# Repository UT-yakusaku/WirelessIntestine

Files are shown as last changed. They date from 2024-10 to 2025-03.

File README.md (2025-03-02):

This is the code for a paper titiled "Wireless Recording and Autoencoder Denoising of Intestinal Activity in Freely Moving Rats"

# WirelessIntestine

In this repository, we have 3 main components used in our paper.

`kicad/` : PCB and BOM of a custom-made board  
`nrf/` : a custom-made firmware for microcontroller (nrf51822)  
`analysis/model_train.py`: codes for training the denoising autoencoder  

## Building a firmware for nrf51822

Building and flashing firmware were described in the Makefile routines.
Connect the debugger to the microcontroller via JTAG, then build and flash the program using:

```
cd nrf/
make . -B ./_build
make flash_softdevice
```

## Detailed description of methods

Below, detailed description of analysis methods utilized in paper.

## Locomotion index

Locomotion index was calculated by the video of behaving rats in their homecage, recorded at a resolution of 960 by 540 pixels squared at 30 frames per second. As an initial preprocessing step for analyzing rats’ locomotion, video frames were converted to grayscale, with frames extracted every 180 frames (downsampled). The differential between successive frames was employed to quantify the magnitude of locomotion at each temporal point. In calculating this specific differential, the variance between the luminance values in each pixel, ranging from 0 to 255, was computed for every frame and aggregated across the entire frame. These aggregated values were designated as the locomotion levels and interpreted as an index of the rat's activity at specific intervals.
Locomotion levels were measured throughout the entire recording period. Home cage provided a confined space, restricting the variety of locomotion. Given this limitation, we estimated that their movements under these experimental conditions could be classified into two distinct states: moving (behaving) and non-moving (immobile). A Gaussian mixture model (GMM) was used to classify these states and determine the threshold for the locomotion index.

## Calculation of alpha in power-law noises

Alpha (α) is a parameter of power-law noise that defines the slope of the spectrum. Specifically, α is determined by the following relationship:
Where f is the frequency and S(f) is the power spectral density (PSD) of the power-law noise,
S(f) ∝ f ^(-α)
This equation indicates that a higher α corresponds to a steeper spectral slope, while a lower α results in a flatter spectrum in the Fourier-transformed waveforms. 

For the analysis of intestinal movement signals, a Fourier transform was applied to the acquired signals and represented on a double-logarithmic graph (Figure 1C, 2D). The signal comprising 180,000 data points was limited within the frequency range up to 5 Hz resulting in 18,000 points, meticulously smoothed employing a third-order Savitzky-Golay filter with a window size of 51, as executed via the Python Scikit-learn library. For the analysis across both logarithmic graphs, the smoothed signal was resampled at uniformly distributed intervals with a scaling factor of 100.02 in the logarithmic domain to circumvent bias in the subsequent fitting procedure. This precaution addresses the intrinsic characteristic of data sampled in linear space, which predisposes it to contain more data points in high-frequency regions as opposed to the low-frequency areas, resulting in their disproportionate representation when analyzed on a logarithmic scale. The resampled signal to mitigate this biased representation was depicted on a logarithmic scale spanning from 5 × 10⁻⁴ to 5 Hz, and thereafter, it was meticulously fitted with a linear function utilizing the least-squares methodology. This linear fit was employed to estimate a robust baseline for evaluating the strength of intestinal movement and calculate the slope of baseline, interpreted as the alpha.

## Definition of Intestinal Events

The amplitude of intestinal movements was segmented into 10.24-second bins. These amplitudes were then classified into two states—containing or lacking intestinal activity—using a Gaussian mixture model (the number of components is set to 2). Intestinal events were defined as periods in which intestinal activity was present.

## Autoencoder construction and training

### Training datasets

The training data comprised scalograms derived from amplitude-modulated waves, representing pure intestinal movements, amalgamated with pink noise to simulate motion-induced disruptions. The pure signal was modeled as the product of a modulation sine wave (frequency: 0.01-0.2 Hz) and a carrier wave (frequency: 0.5-0.7 Hz), with its intensity and frequency, varied across training samples to introduce diversity. Pink noise, inversely proportional to frequency, was incorporated to emulate movement artifacts, with a 15-fold difference in noise intensity between high- and low-noise conditions. The model was trained with 100 artificial 2000-second waves. The model was engineered to receive the high-noise version of signals as input and produce the low-noise version as output. The dataset was split into training and validation groups at an 8:2 ratio.

### Data preprocessing

For preprocessing, signals were converted into scalograms utilizing a short-term Fourier transform (STFT) with a 10.24-second Hann window, providing a frequency resolution of 0.1 Hz. These scalograms, restricted to the 0.4–6.5 Hz range, were segmented into 655-second segments and resized into 64 × 64 matrices for input into the autoencoder.

### Model construction

The autoencoder architecture comprises three parts: the encoder, bottleneck, and decoder. The encoder first processes the input matrices through a 2D convolutional layer with 32 filters of size 3 × 3, followed by a 2 × 2 max-pooling layer, reducing the matrices to 32 × 32 × 32. A second convolutional layer with identical filter dimensions and another max-pooling layer further reduces the size to 64 × 16 × 16. A 2D convolutional operation is performed in the bottleneck layer, increasing the depth to 128 while maintaining the spatial dimensions.
In the decoder, two upsampling layers, each followed by a convolutional layer, sequentially doubled the spatial dimensions and reduced the depth, ultimately restoring the matrices to 32 × 64 × 64. The final convolutional layer employed a linear activation function to conform the output to the input dimensions.

### Training

The model was trained to utilize the Adam optimizer with a learning rate of 0.001 and mean squared error (MSE) as the loss function. The training was confined to 100 epochs, with the learning rate reduced by a factor of 0.1 after five epochs without improvement. If no improvement was observed after ten epochs, training was stopped early. All routines were implemented using Python TensorFlow and Keras libraries.

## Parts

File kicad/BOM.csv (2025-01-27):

Item # | Ref Des | Qty | Manufacturer | Mfg Part # | Description / Value | Package | Type
1 | U1 | 1 | Analog Devices | AD8237ARMZ | IC AMP MSOP-8 | MSOP-8_3x3mm_P0.65mm | SMD
2 | U2 | 1 | Texas Instruments | ADS1113IDGST | IC ADC 16BITS 860SPS VSSOP-10 | VSSOP-10_3x3mm_P0.5mm | SMD
3 | U3 | 1 | Texas Instruments | TLV71330PDBVR | IC LDO REG SOT-23-5 | SOT-23-5 | SMD
4 | R1,R2,R3 | 3 | Panasonic | ERA-3AEB121V | RES 120 OHM 0.1% 0603 SMD | R_0603_1608Metric | SMD
5 | R4,R5 | 2 | ROHM | MCR03ERTF4300 | RES 430 OHM 1.0% 0603 SMD | R_0603_1608Metric | SMD
6 | R6 | 1 | Panasonic | ERA-3AED104V | RES 100K OHM 0.5% 0603 SMD | R_0603_1608Metric | SMD
7 | R7,R8 | 2 | ROHM | MCR01MZPF1002 | RES 10K OHM 1.0% 0603 SMD | R_0402_1005Metric | SMD
8 | C1,C2,C3,C4 | 4 | TDK | C1005X5R1V104K | CAP MLCC 0.1UF 0402 SMD | C_0402_1005Metric | SMD
9 | C5 | 1 | TDK | CGA6N2C0G2A473J | CAP MLCC .047UF 3225 SMD | C_1210_3225Metric | SMD

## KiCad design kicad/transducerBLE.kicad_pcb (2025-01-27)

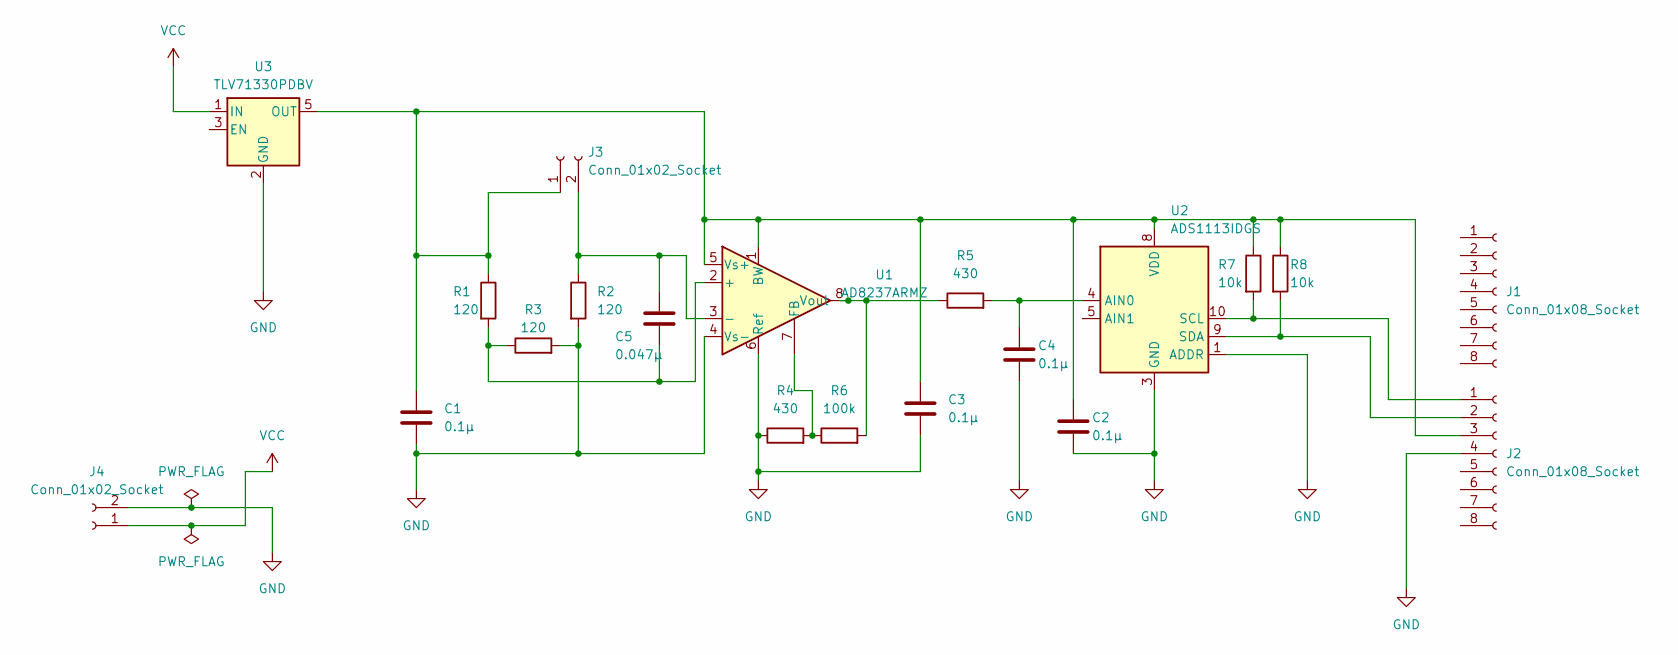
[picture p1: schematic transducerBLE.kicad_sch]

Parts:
C1, C2, C3, C4: 0.1µ; C_0402_1005Metric
C5: 0.047µ; C_1210_3225Metric
J1, J2: Conn_01x08_Socket; PinSocket_1x08_P2.54mm_Vertical
J3, J4: Conn_01x02_Socket; PinSocket_1x02_P2.00mm_Horizontal
R1, R2, R3: 120; R_0603_1608Metric
R4, R5: 430; R_0603_1608Metric
R6: 100k; R_0603_1608Metric
R7, R8: 10k; R_0402_1005Metric
U1: AD8237ARMZ; MSOP-8_3x3mm_P0.65mm
U2: ADS1113IDGS; TSSOP-10_3x3mm_P0.5mm
U3: TLV71330PDBV; SOT-23-5

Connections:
GND: C1.2, C2.2, C3.2, C4.2, J2.4, J4.2, R2.2, R3.2, R4.1, U1.4 (Vs-), U1.6 (Ref), U2.1 (ADDR), U2.3 (GND), U3.2 (GND)
unnamed: J2.1, R7.2, U2.10 (SCL)
unnamed: J2.2, R8.2, U2.9 (SDA)
unnamed: C1.1, C2.1, C3.1, J2.3, J3.1, R1.1, R7.1, R8.1, U1.1 (BW), U1.5 (Vs+), U2.8 (VDD), U3.5 (OUT)
unnamed: C5.1, J3.2, R2.1, U1.3 (-)
unnamed: C5.2, R1.2, R3.1, U1.2 (+)
unnamed: R4.2, R6.1, U1.7 (FB)
unnamed: R5.1, R6.2, U1.8 (Vout)
unnamed: C4.1, R5.2, U2.4 (AIN0)
VCC: J4.1, U3.1 (IN)

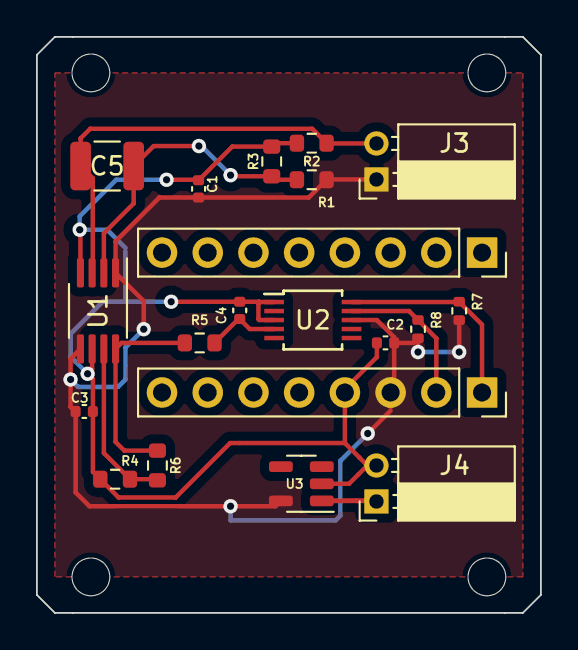
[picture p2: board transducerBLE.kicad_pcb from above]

Board: 2 copper layers, 28.0 x 32.0 mm, 20 parts (0 on the bottom side), 10 nets.

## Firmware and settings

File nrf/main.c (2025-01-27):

/**
 * Copyright (c) 2014 - 2017, Nordic Semiconductor ASA
 * 
 * All rights reserved.
 * 
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
 * 3. Neither the name of Nordic Semiconductor ASA nor the names of its
 *    contributors may be used to endorse or promote products derived from this
 *    software without specific prior written permission.
 * 
 * 4. This software, with or without modification, must only be used with a
 *    Nordic Semiconductor ASA integrated circuit.
 * 
 * 5. Any software provided in binary form under this license must not be reverse
 *    engineered, decompiled, modified and/or disassembled.
 * 
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
 */

/** @file
 *
 * @defgroup ble_sdk_uart_over_ble_main main.c
 * @{
 * @ingroup  ble_sdk_app_nus_eval
 * @brief    UART over BLE application main file.
 *
 * This file contains the source code for a sample application that uses the Nordic UART service.
 * This application uses the @ref srvlib_conn_params module.
 */

#include <stdint.h>
#include <string.h>
#include "nordic_common.h"
#include "nrf.h"
#include "ble_hci.h"
#include "ble_advdata.h"
#include "ble_advertising.h"
#include "ble_conn_params.h"
#include "softdevice_handler.h"
#include "app_timer.h"
#include "app_button.h"
#include "ble_nus.h"
#include "app_uart.h"
#include "app_util_platform.h"
#include "bsp.h"
#include "bsp_btn_ble.h"
#include "drivers_nrf/timer/nrf_drv_timer.h"
#include "drivers_nrf/twi_master/nrf_drv_twi.h"

#define IS_SRVC_CHANGED_CHARACT_PRESENT 0                                           /**< Include the service_changed characteristic. If not enabled, the server's database cannot be changed for the lifetime of the device. */

#if (NRF_SD_BLE_API_VERSION == 3)
#define NRF_BLE_MAX_MTU_SIZE            GATT_MTU_SIZE_DEFAULT                       /**< MTU size used in the softdevice enabling and to reply to a BLE_GATTS_EVT_EXCHANGE_MTU_REQUEST event. */
#endif

#define APP_FEATURE_NOT_SUPPORTED       BLE_GATT_STATUS_ATTERR_APP_BEGIN + 2        /**< Reply when unsupported features are requested. */

#define CENTRAL_LINK_COUNT              0                                           /**< Number of central links used by the application. When changing this number remember to adjust the RAM settings*/
#define PERIPHERAL_LINK_COUNT           1                                           /**< Number of peripheral links used by the application. When changing this number remember to adjust the RAM settings*/

#define DEVICE_NAME                     "Nordic_UART"                               /**< Name of device. Will be included in the advertising data. */
#define NUS_SERVICE_UUID_TYPE           BLE_UUID_TYPE_VENDOR_BEGIN                  /**< UUID type for the Nordic UART Service (vendor specific). */

#define APP_ADV_INTERVAL                256//64                                          /**< The advertising interval (in units of 0.625 ms. This value corresponds to 40 ms). */
#define APP_ADV_TIMEOUT_IN_SECONDS      0                                           /**< The advertising timeout (in units of seconds). */

#define APP_TIMER_PRESCALER             0                                           /**< Value of the RTC1 PRESCALER register. */
#define APP_TIMER_OP_QUEUE_SIZE         4                                           /**< Size of timer operation queues. */

#define MIN_CONN_INTERVAL               MSEC_TO_UNITS(20, UNIT_1_25_MS)             /**< Minimum acceptable connection interval (20 ms), Connection interval uses 1.25 ms units. */
#define MAX_CONN_INTERVAL               MSEC_TO_UNITS(75, UNIT_1_25_MS)             /**< Maximum acceptable connection interval (75 ms), Connection interval uses 1.25 ms units. */
#define SLAVE_LATENCY                   0                                           /**< Slave latency. */
#define CONN_SUP_TIMEOUT                MSEC_TO_UNITS(4000, UNIT_10_MS)             /**< Connection supervisory timeout (4 seconds), Supervision Timeout uses 10 ms units. */
#define FIRST_CONN_PARAMS_UPDATE_DELAY  APP_TIMER_TICKS(5000, APP_TIMER_PRESCALER)  /**< Time from initiating event (connect or start of notification) to first time sd_ble_gap_conn_param_update is called (5 seconds). */
#define NEXT_CONN_PARAMS_UPDATE_DELAY   APP_TIMER_TICKS(30000, APP_TIMER_PRESCALER) /**< Time between each call to sd_ble_gap_conn_param_update after the first call (30 seconds). */
#define MAX_CONN_PARAMS_UPDATE_COUNT    3                                           /**< Number of attempts before giving up the connection parameter negotiation. */

#define DEAD_BEEF                       0xDEADBEEF                                  /**< Value used as error code on stack dump, can be used to identify stack location on stack unwind. */

#define UART_TX_BUF_SIZE                256                                         /**< UART TX buffer size. */
#define UART_RX_BUF_SIZE                256                                         /**< UART RX buffer size. */

static ble_nus_t                        m_nus;                                      /**< Structure to identify the Nordic UART Service. */
static uint16_t                         m_conn_handle = BLE_CONN_HANDLE_INVALID;    /**< Handle of the current connection. */

static ble_uuid_t                       m_adv_uuids[] = {{BLE_UUID_NUS_SERVICE, NUS_SERVICE_UUID_TYPE}};  /**< Universally unique service identifier. */

#define SAMPLE_RATE                     100
#define LOOP_DURATION                   31250 / SAMPLE_RATE

#define TWI_INSTANCE_ID                 0                                           /* TWI instance ID. */
#define TWI_TIMEOUT 			        10000 
#define ADS1115_ADDR                    0x48U                                       /* Common addresses definition for temperature sensor. */
#define SCL_PIN                         17
#define SDA_PIN                         23

#define SWAP(a, b) do { a ^= b; b ^= a; a ^= b; } while(0)

static const nrf_drv_twi_t m_twi        = NRF_DRV_TWI_INSTANCE(TWI_INSTANCE_ID);    /* TWI instance. */
volatile static bool twi_tx_done = false;
volatile static bool twi_rx_done = false;

volatile static uint8_t data_buf[20];
volatile static uint8_t data_buf_to_send[20];
volatile static int8_t data_buf_seek = 0;
volatile static bool data_send_lock = false;

/**@brief Function for assert macro callback.
 *
 * @details This function will be called in case of an assert in the SoftDevice.
 *
 * @warning This handler is an example only and does not fit a final product. You need to analyse
 *          how your product is supposed to react in case of Assert.
 * @warning On assert from the SoftDevice, the system can only recover on reset.
 *
 * @param[in] line_num    Line number of the failing ASSERT call.
 * @param[in] p_file_name File name of the failing ASSERT call.
 */
void assert_nrf_callback(uint16_t line_num, const uint8_t * p_file_name)
{
    app_error_handler(DEAD_BEEF, line_num, p_file_name);
}


/**@brief Function for the GAP initialization.
 *
 * @details This function will set up all the necessary GAP (Generic Access Profile) parameters of
 *          the device. It also sets the permissions and appearance.
 */
static void gap_params_init(void)
{
    uint32_t                err_code;
    ble_gap_conn_params_t   gap_conn_params;
    ble_gap_conn_sec_mode_t sec_mode;

    BLE_GAP_CONN_SEC_MODE_SET_OPEN(&sec_mode);

    err_code = sd_ble_gap_device_name_set(&sec_mode,
                                          (const uint8_t *) DEVICE_NAME,
                                          strlen(DEVICE_NAME));
    APP_ERROR_CHECK(err_code);

    memset(&gap_conn_params, 0, sizeof(gap_conn_params));

    gap_conn_params.min_conn_interval = MIN_CONN_INTERVAL;
    gap_conn_params.max_conn_interval = MAX_CONN_INTERVAL;
    gap_conn_params.slave_latency     = SLAVE_LATENCY;
    gap_conn_params.conn_sup_timeout  = CONN_SUP_TIMEOUT;

    err_code = sd_ble_gap_ppcp_set(&gap_conn_params);
    APP_ERROR_CHECK(err_code);
}


/**@brief Function for handling the data from the Nordic UART Service.
 *
 * @details This function will process the data received from the Nordic UART BLE Service and send
 *          it to the UART module.
 *
 * @param[in] p_nus    Nordic UART Service structure.
 * @param[in] p_data   Data to be send to UART module.
 * @param[in] length   Length of the data.
 */
/**@snippet [Handling the data received over BLE] */
static void nus_data_handler(ble_nus_t * p_nus, uint8_t * p_data, uint16_t length)
{
    for (uint32_t i = 0; i < length; i++)
    {
        while (app_uart_put(p_data[i]) != NRF_SUCCESS);
    }
    while (app_uart_put('\r') != NRF_SUCCESS);
    while (app_uart_put('\n') != NRF_SUCCESS);
}
/**@snippet [Handling the data received over BLE] */


/**@brief Function for initializing services that will be used by the application.
 */
static void services_init(void)
{
    uint32_t       err_code;
    ble_nus_init_t nus_init;

    memset(&nus_init, 0, sizeof(nus_init));

    nus_init.data_handler = nus_data_handler;

    err_code = ble_nus_init(&m_nus, &nus_init);
    APP_ERROR_CHECK(err_code);
}


/**@brief Function for handling an event from the Connection Parameters Module.
 *
 * @details This function will be called for all events in the Connection Parameters Module
 *          which are passed to the application.
 *
 * @note All this function does is to disconnect. This could have been done by simply setting
 *       the disconnect_on_fail config parameter, but instead we use the event handler
 *       mechanism to demonstrate its use.
 *
 * @param[in] p_evt  Event received from the Connection Parameters Module.
 */
static void on_conn_params_evt(ble_conn_params_evt_t * p_evt)
{
    uint32_t err_code;

    if (p_evt->evt_type == BLE_CONN_PARAMS_EVT_FAILED)
    {
        err_code = sd_ble_gap_disconnect(m_conn_handle, BLE_HCI_CONN_INTERVAL_UNACCEPTABLE);
        APP_ERROR_CHECK(err_code);
    }
}


/**@brief Function for handling errors from the Connection Parameters module.
 *
 * @param[in] nrf_error  Error code containing information about what went wrong.
 */
static void conn_params_error_handler(uint32_t nrf_error)
{
    APP_ERROR_HANDLER(nrf_error);
}


/**@brief Function for initializing the Connection Parameters module.
 */
static void conn_params_init(void)
{
    uint32_t               err_code;
    ble_conn_params_init_t cp_init;

    memset(&cp_init, 0, sizeof(cp_init));

    cp_init.p_conn_params                  = NULL;
    cp_init.first_conn_params_update_delay = FIRST_CONN_PARAMS_UPDATE_DELAY;
    cp_init.next_conn_params_update_delay  = NEXT_CONN_PARAMS_UPDATE_DELAY;
    cp_init.max_conn_params_update_count   = MAX_CONN_PARAMS_UPDATE_COUNT;
    cp_init.start_on_notify_cccd_handle    = BLE_GATT_HANDLE_INVALID;
    cp_init.disconnect_on_fail             = false;
    cp_init.evt_handler                    = on_conn_params_evt;
    cp_init.error_handler                  = conn_params_error_handler;

    err_code = ble_conn_params_init(&cp_init);
    APP_ERROR_CHECK(err_code);
}


/**@brief Function for putting the chip into sleep mode.
 *
 * @note This function will not return.
 */
static void sleep_mode_enter(void)
{
    uint32_t err_code = bsp_indication_set(BSP_INDICATE_IDLE);
    APP_ERROR_CHECK(err_code);

    // Prepare wakeup buttons.
    err_code = bsp_btn_ble_sleep_mode_prepare();
    APP_ERROR_CHECK(err_code);

    // Go to system-off mode (this function will not return; wakeup will cause a reset).
    err_code = sd_power_system_off();
    APP_ERROR_CHECK(err_code);
}


/**@brief Function for handling advertising events.
 *
 * @details This function will be called for advertising events which are passed to the application.
 *
 * @param[in] ble_adv_evt  Advertising event.
 */
static void on_adv_evt(ble_adv_evt_t ble_adv_evt)
{
    uint32_t err_code;

    switch (ble_adv_evt)
    {
        case BLE_ADV_EVT_FAST:
            err_code = bsp_indication_set(BSP_INDICATE_ADVERTISING);
            APP_ERROR_CHECK(err_code);
            break;
        case BLE_ADV_EVT_IDLE:
            sleep_mode_enter();
            break;
        default:
            break;
    }
}


/**@brief Function for the application's SoftDevice event handler.
 *
 * @param[in] p_ble_evt SoftDevice event.
 */
static void on_ble_evt(ble_evt_t * p_ble_evt)
{
    uint32_t err_code;

    switch (p_ble_evt->header.evt_id)
    {
        case BLE_GAP_EVT_CONNECTED:
            err_code = bsp_indication_set(BSP_INDICATE_CONNECTED);
            APP_ERROR_CHECK(err_code);
            m_conn_handle = p_ble_evt->evt.gap_evt.conn_handle;
            break; // BLE_GAP_EVT_CONNECTED

        case BLE_GAP_EVT_DISCONNECTED:
            err_code = bsp_indication_set(BSP_INDICATE_IDLE);
            APP_ERROR_CHECK(err_code);
            m_conn_handle = BLE_CONN_HANDLE_INVALID;
            break; // BLE_GAP_EVT_DISCONNECTED

        case BLE_GAP_EVT_SEC_PARAMS_REQUEST:
            // Pairing not supported
            err_code = sd_ble_gap_sec_params_reply(m_conn_handle, BLE_GAP_SEC_STATUS_PAIRING_NOT_SUPP, NULL, NULL);
            APP_ERROR_CHECK(err_code);
            break; // BLE_GAP_EVT_SEC_PARAMS_REQUEST

        case BLE_GATTS_EVT_SYS_ATTR_MISSING:
            // No system attributes have been stored.
            err_code = sd_ble_gatts_sys_attr_set(m_conn_handle, NULL, 0, 0);
            APP_ERROR_CHECK(err_code);
            break; // BLE_GATTS_EVT_SYS_ATTR_MISSING

        case BLE_GATTC_EVT_TIMEOUT:
            // Disconnect on GATT Client timeout event.
            err_code = sd_ble_gap_disconnect(p_ble_evt->evt.gattc_evt.conn_handle,
                                             BLE_HCI_REMOTE_USER_TERMINATED_CONNECTION);
            APP_ERROR_CHECK(err_code);
            break; // BLE_GATTC_EVT_TIMEOUT

        case BLE_GATTS_EVT_TIMEOUT:
            // Disconnect on GATT Server timeout event.
            err_code = sd_ble_gap_disconnect(p_ble_evt->evt.gatts_evt.conn_handle,
                                             BLE_HCI_REMOTE_USER_TERMINATED_CONNECTION);
            APP_ERROR_CHECK(err_code);
            break; // BLE_GATTS_EVT_TIMEOUT

        case BLE_EVT_USER_MEM_REQUEST:
            err_code = sd_ble_user_mem_reply(p_ble_evt->evt.gattc_evt.conn_handle, NULL);
            APP_ERROR_CHECK(err_code);
            break; // BLE_EVT_USER_MEM_REQUEST

        case BLE_GATTS_EVT_RW_AUTHORIZE_REQUEST:
        {
            ble_gatts_evt_rw_authorize_request_t  req;
            ble_gatts_rw_authorize_reply_params_t auth_reply;

            req = p_ble_evt->evt.gatts_evt.params.authorize_request;

            if (req.type != BLE_GATTS_AUTHORIZE_TYPE_INVALID)
            {
                if ((req.request.write.op == BLE_GATTS_OP_PREP_WRITE_REQ)     ||
                    (req.request.write.op == BLE_GATTS_OP_EXEC_WRITE_REQ_NOW) ||
                    (req.request.write.op == BLE_GATTS_OP_EXEC_WRITE_REQ_CANCEL))
                {
                    if (req.type == BLE_GATTS_AUTHORIZE_TYPE_WRITE)
                    {
                        auth_reply.type = BLE_GATTS_AUTHORIZE_TYPE_WRITE;
                    }
                    else
                    {
                        auth_reply.type = BLE_GATTS_AUTHORIZE_TYPE_READ;
                    }
                    auth_reply.params.write.gatt_status = APP_FEATURE_NOT_SUPPORTED;
                    err_code = sd_ble_gatts_rw_authorize_reply(p_ble_evt->evt.gatts_evt.conn_handle,
                                                               &auth_reply);
                    APP_ERROR_CHECK(err_code);
                }
            }
        } break; // BLE_GATTS_EVT_RW_AUTHORIZE_REQUEST

#if (NRF_SD_BLE_API_VERSION == 3)
        case BLE_GATTS_EVT_EXCHANGE_MTU_REQUEST:
            err_code = sd_ble_gatts_exchange_mtu_reply(p_ble_evt->evt.gatts_evt.conn_handle,
                                                       NRF_BLE_MAX_MTU_SIZE);
            APP_ERROR_CHECK(err_code);
            break; // BLE_GATTS_EVT_EXCHANGE_MTU_REQUEST
#endif

        default:
            // No implementation needed.
            break;
    }
}


/**@brief Function for dispatching a SoftDevice event to all modules with a SoftDevice
 *        event handler.
 *
 * @details This function is called from the SoftDevice event interrupt handler after a
 *          SoftDevice event has been received.
 *
 * @param[in] p_ble_evt  SoftDevice event.
 */
static void ble_evt_dispatch(ble_evt_t * p_ble_evt)
{
    ble_conn_params_on_ble_evt(p_ble_evt);
    ble_nus_on_ble_evt(&m_nus, p_ble_evt);
    on_ble_evt(p_ble_evt);
    ble_advertising_on_ble_evt(p_ble_evt);
    bsp_btn_ble_on_ble_evt(p_ble_evt);

}


/**@brief Function for the SoftDevice initialization.
 *
 * @details This function initializes the SoftDevice and the BLE event interrupt.
 */
static void ble_stack_init(void)
{
    uint32_t err_code;

    //nrf_clock_lf_cfg_t clock_lf_cfg = NRF_CLOCK_LFCLKSRC;
    nrf_clock_lf_cfg_t clock_lf_cfg;
    clock_lf_cfg.rc_ctiv = 16;
    clock_lf_cfg.rc_temp_ctiv = 2;
    clock_lf_cfg.source = NRF_CLOCK_LF_SRC_RC;
    clock_lf_cfg.xtal_accuracy = NRF_CLOCK_LF_XTAL_ACCURACY_250_PPM;

    // Initialize SoftDevice.
    SOFTDEVICE_HANDLER_INIT(&clock_lf_cfg, NULL);

    ble_enable_params_t ble_enable_params;
    err_code = softdevice_enable_get_default_config(CENTRAL_LINK_COUNT,
                                                    PERIPHERAL_LINK_COUNT,
                                                    &ble_enable_params);
    APP_ERROR_CHECK(err_code);

    //Check the ram settings against the used number of links
    CHECK_RAM_START_ADDR(CENTRAL_LINK_COUNT,PERIPHERAL_LINK_COUNT);

    // Enable BLE stack.
#if (NRF_SD_BLE_API_VERSION == 3)
    ble_enable_params.gatt_enable_params.att_mtu = NRF_BLE_MAX_MTU_SIZE;
#endif
    err_code = softdevice_enable(&ble_enable_params);
    APP_ERROR_CHECK(err_code);

    // Subscribe for BLE events.
    err_code = softdevice_ble_evt_handler_set(ble_evt_dispatch);
    APP_ERROR_CHECK(err_code);
}


/**@brief Function for handling events from the BSP module.
 *
 * @param[in]   event   Event generated by button press.
 */
void bsp_event_handler(bsp_event_t event)
{
    uint32_t err_code;
    switch (event)
    {
        case BSP_EVENT_SLEEP:
            sleep_mode_enter();
            break;

        case BSP_EVENT_DISCONNECT:
            err_code = sd_ble_gap_disconnect(m_conn_handle, BLE_HCI_REMOTE_USER_TERMINATED_CONNECTION);
            if (err_code != NRF_ERROR_INVALID_STATE)
            {
                APP_ERROR_CHECK(err_code);
            }
            break;

        case BSP_EVENT_WHITELIST_OFF:
            if (m_conn_handle == BLE_CONN_HANDLE_INVALID)
            {
                err_code = ble_advertising_restart_without_whitelist();
                if (err_code != NRF_ERROR_INVALID_STATE)
                {
                    APP_ERROR_CHECK(err_code);
                }
            }
            break;

        default:
            break;
    }
}


/**@brief   Function for handling app_uart events.
 *
 * @details This function will receive a single character from the app_uart module and append it to
 *          a string. The string will be be sent over BLE when the last character received was a
 *          'new line' i.e '\r\n' (hex 0x0D) or if the string has reached a length of
 *          @ref NUS_MAX_DATA_LENGTH.
 */
/**@snippet [Handling the data received over UART] */
void uart_event_handle(app_uart_evt_t * p_event)
{
    static uint8_t data_array[BLE_NUS_MAX_DATA_LEN];
    static uint8_t index = 0;
    uint32_t       err_code;

    switch (p_event->evt_type)
    {
        case APP_UART_DATA_READY:
            UNUSED_VARIABLE(app_uart_get(&data_array[index]));
            index++;

            if ((data_array[index - 1] == '\n') || (index >= (BLE_NUS_MAX_DATA_LEN)))
            {
                err_code = ble_nus_string_send(&m_nus, data_array, index);
                if (err_code != NRF_ERROR_INVALID_STATE)
                {
                    APP_ERROR_CHECK(err_code);
                }

                index = 0;
            }
            break;

        case APP_UART_COMMUNICATION_ERROR:
            APP_ERROR_HANDLER(p_event->data.error_communication);
            break;

        case APP_UART_FIFO_ERROR:
            APP_ERROR_HANDLER(p_event->data.error_code);
            break;

        default:
            break;
    }
}
/**@snippet [Handling the data received over UART] */
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
int main(void)
{
    uint32_t err_code;
    bool erase_bonds;

    // Initialize.
    APP_TIMER_INIT(APP_TIMER_PRESCALER, APP_TIMER_OP_QUEUE_SIZE, false);
    uart_init();

    buttons_leds_init(&erase_bonds);
    ble_stack_init();
    gap_params_init();
    services_init();
    advertising_init();
    conn_params_init();
    twi_init();
    start_timer();
    ADS1115_set_mode();

    printf("\r\nUART Start!\r\n");
    err_code = ble_advertising_start(BLE_ADV_MODE_FAST);
    APP_ERROR_CHECK(err_code);

    uint16_t count = 0;

    // Enter main loop.
    for (;;)
    {
        // uint8_t a[2];
        // read_sensor_data(a);
        // ble_attempt_to_send(a, 2);
        if (data_send_lock) {
            data_buf_to_send[18] = count % 256;
            data_buf_to_send[19] = count / 256;
            ble_attempt_to_send(data_buf_to_send, 20);
            count++;
            data_send_lock = false;
        }
        __WFE();
        __SEV();
        __WFE();
    }
}


/**
 * @}
 */

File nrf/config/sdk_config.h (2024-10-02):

#ifndef SDK_CONFIG_H
#define SDK_CONFIG_H
// <<< Use Configuration Wizard in Context Menu >>>\n
#ifdef USE_APP_CONFIG
#include "app_config.h"
#endif
// <h> nRF_BLE 

//==========================================================
// <q> BLE_ADVERTISING_ENABLED  - ble_advertising - Advertising module
 

#ifndef BLE_ADVERTISING_ENABLED
#define BLE_ADVERTISING_ENABLED 1
#endif

// <q> BLE_DTM_ENABLED  - ble_dtm - Module for testing RF/PHY using DTM commands
 

#ifndef BLE_DTM_ENABLED
#define BLE_DTM_ENABLED 0
#endif

// <q> BLE_RACP_ENABLED  - ble_racp - Record Access Control Point library
 

#ifndef BLE_RACP_ENABLED
#define BLE_RACP_ENABLED 0
#endif

// <q> NRF_BLE_QWR_ENABLED  - nrf_ble_qwr - Queued writes support module (prepare/execute write)
 

#ifndef NRF_BLE_QWR_ENABLED
#define NRF_BLE_QWR_ENABLED 0
#endif

// <q> PEER_MANAGER_ENABLED  - peer_manager - Peer Manager
 

#ifndef PEER_MANAGER_ENABLED
#define PEER_MANAGER_ENABLED 0
#endif

// </h> 
//==========================================================

// <h> nRF_BLE_Services 

//==========================================================
// <q> BLE_ANCS_C_ENABLED  - ble_ancs_c - Apple Notification Service Client
 

#ifndef BLE_ANCS_C_ENABLED
#define BLE_ANCS_C_ENABLED 0
#endif

// <q> BLE_ANS_C_ENABLED  - ble_ans_c - Alert Notification Service Client
 

#ifndef BLE_ANS_C_ENABLED
#define BLE_ANS_C_ENABLED 0
#endif

// <q> BLE_BAS_C_ENABLED  - ble_bas_c - Battery Service Client
 

#ifndef BLE_BAS_C_ENABLED
#define BLE_BAS_C_ENABLED 0
#endif

// <q> BLE_BAS_ENABLED  - ble_bas - Battery Service
 

#ifndef BLE_BAS_ENABLED
#define BLE_BAS_ENABLED 0
#endif

// <q> BLE_CSCS_ENABLED  - ble_cscs - Cycling Speed and Cadence Service
 

#ifndef BLE_CSCS_ENABLED
#define BLE_CSCS_ENABLED 0
#endif

// <q> BLE_CTS_C_ENABLED  - ble_cts_c - Current Time Service Client
 

#ifndef BLE_CTS_C_ENABLED
#define BLE_CTS_C_ENABLED 0
#endif

// <q> BLE_DIS_ENABLED  - ble_dis - Device Information Service
 

#ifndef BLE_DIS_ENABLED
#define BLE_DIS_ENABLED 0
#endif

// <q> BLE_GLS_ENABLED  - ble_gls - Glucose Service
 

#ifndef BLE_GLS_ENABLED
#define BLE_GLS_ENABLED 0
#endif

// <q> BLE_HIDS_ENABLED  - ble_hids - Human Interface Device Service
 

#ifndef BLE_HIDS_ENABLED
#define BLE_HIDS_ENABLED 0
#endif

// <e> BLE_HRS_C_ENABLED - ble_hrs_c - Heart Rate Service Client
//==========================================================
#ifndef BLE_HRS_C_ENABLED
#define BLE_HRS_C_ENABLED 0
#endif
#if  BLE_HRS_C_ENABLED
// <o> BLE_HRS_C_RR_INTERVALS_MAX_CNT - Maximum number of RR_INTERVALS per notification to be decoded 
#ifndef BLE_HRS_C_RR_INTERVALS_MAX_CNT
#define BLE_HRS_C_RR_INTERVALS_MAX_CNT 30
#endif

#endif //BLE_HRS_C_ENABLED
// </e>

// <q> BLE_HRS_ENABLED  - ble_hrs - Heart Rate Service
 

#ifndef BLE_HRS_ENABLED
#define BLE_HRS_ENABLED 0
#endif

// <q> BLE_HTS_ENABLED  - ble_hts - Health Thermometer Service
 

#ifndef BLE_HTS_ENABLED
#define BLE_HTS_ENABLED 0
#endif

// <q> BLE_IAS_C_ENABLED  - ble_ias_c - Immediate Alert Service Client
 

#ifndef BLE_IAS_C_ENABLED
#define BLE_IAS_C_ENABLED 0
#endif

// <q> BLE_IAS_ENABLED  - ble_ias - Immediate Alert Service
 

#ifndef BLE_IAS_ENABLED
#define BLE_IAS_ENABLED 0
#endif

// <q> BLE_LBS_C_ENABLED  - ble_lbs_c - Nordic LED Button Service Client
 

#ifndef BLE_LBS_C_ENABLED
#define BLE_LBS_C_ENABLED 0
#endif

// <q> BLE_LBS_ENABLED  - ble_lbs - LED Button Service
 

#ifndef BLE_LBS_ENABLED
#define BLE_LBS_ENABLED 0
#endif

// <q> BLE_LLS_ENABLED  - ble_lls - Link Loss Service
 

#ifndef BLE_LLS_ENABLED
#define BLE_LLS_ENABLED 0
#endif

// <q> BLE_NUS_C_ENABLED  - ble_nus_c - Nordic UART Central Service
 

#ifndef BLE_NUS_C_ENABLED
#define BLE_NUS_C_ENABLED 0
#endif

// <q> BLE_NUS_ENABLED  - ble_nus - Nordic UART Service
 

#ifndef BLE_NUS_ENABLED
#define BLE_NUS_ENABLED 1
#endif

// <q> BLE_RSCS_C_ENABLED  - ble_rscs_c - Running Speed and Cadence Client
 

#ifndef BLE_RSCS_C_ENABLED
#define BLE_RSCS_C_ENABLED 0
#endif

// <q> BLE_RSCS_ENABLED  - ble_rscs - Running Speed and Cadence Service
 

#ifndef BLE_RSCS_ENABLED
#define BLE_RSCS_ENABLED 0
#endif

// <q> BLE_TPS_ENABLED  - ble_tps - TX Power Service
 

#ifndef BLE_TPS_ENABLED
#define BLE_TPS_ENABLED 0
#endif

// </h> 
//==========================================================

// <h> nRF_Drivers 

//==========================================================
// <e> ADC_ENABLED - nrf_drv_adc - Driver for ADC peripheral (nRF51)
//==========================================================
#ifndef ADC_ENABLED
#define ADC_ENABLED 0
#endif
#if  ADC_ENABLED
// <o> ADC_CONFIG_IRQ_PRIORITY  - Interrupt priority
 

// <i> Priorities 0,2 (nRF51) and 0,1,4,5 (nRF52) are reserved for SoftDevice
// <0=> 0 (highest) 
// <1=> 1 
// <2=> 2 
// <3=> 3 

#ifndef ADC_CONFIG_IRQ_PRIORITY
#define ADC_CONFIG_IRQ_PRIORITY 3
#endif
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

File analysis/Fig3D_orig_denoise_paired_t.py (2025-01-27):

import os
from scipy.stats import ttest_rel
from scipy.signal import find_peaks
from sklearn.mixture import GaussianMixture

import numpy as np
import matplotlib.pyplot as plt
from matplotlib.colors import LogNorm 
import h5py
from scipy.signal import stft
from tensorflow.keras.models import Model, load_model
from tensorflow.keras.layers import Input, Dense
from tensorflow.keras.optimizers import Adam
from tensorflow.keras.layers import Conv2D, MaxPooling2D, UpSampling2D, Dropout, BatchNormalization, Input, Reshape
from tensorflow.keras.callbacks import EarlyStopping, ReduceLROnPlateau
from tqdm import tqdm
import os
from scipy import signal
import struct
import scipy.stats as stats

def loadData(path):
    data = []
    time = []
    time_diff_ns = 0
    nrow = 0
    time_top = 0
    rowNo_top = 0
    rowNo_loop_cnt = 0
    with open(path, 'rb') as f:
        f.seek(0, os.SEEK_SET)
        if f.read(3).decode("ascii") != "DAT":
            raise Exception
            return
        f.seek(4, os.SEEK_SET)
        nrow = struct.unpack('<L', f.read(4))[0]
        time_diff_ns = struct.unpack('<L', f.read(4))[0]
        time_diff_ms = time_diff_ns // 1000
        f.seek(32, os.SEEK_SET)
        time_top = time_diff_ms
        buf = struct.unpack('>9h', f.read(18))
        rowNo = struct.unpack('<3H', f.read(6))
        print(buf)
        rowNo_top = rowNo[0]
        for j in range(9):
            time.append(time_top + 10000 * j)
            data.append(buf[j])
        while True:
            try:
                buf = struct.unpack('>9h', f.read(18))
                rowNo = struct.unpack('<3H', f.read(6))
            except:
                break
            if rowNo[0] + rowNo_loop_cnt * 65536 < rowNo_top:
                rowNo_loop_cnt += 1
            time_top += (rowNo[0] + rowNo_loop_cnt * 65536 - rowNo_top) * 90000
            rowNo_top = rowNo[0] + rowNo_loop_cnt * 65536
            for j in range(9):
                time.append(time_top + 10000 * j)
                data.append(buf[j])
    return data, time

def convertVolt(data, amp_resistance):
    adc_multiplier = 0.125
    amp_gain = 1.0 + (100000.0 / amp_resistance)
    volt_coeff = adc_multiplier / amp_gain
    return data * volt_coeff

def bandpass(x, samplerate, fp, fs, gpass, gstop):
    fn = samplerate / 2
    wp = fp / fn
    ws = fs / fn
    N, Wn = signal.buttord(wp, ws, gpass, gstop)
    b, a = signal.butter(N, Wn, "band")
    y = signal.filtfilt(b, a, x)
    return y   

# Constants
SAMPLE_RATE = 100  # Samples per second
FREQ = 0.6  # Target frequency in Hz
NOISE_COEFF = (0.8, 1.2)
CHUNK_SIZE = 1024
FFT_SIZE = 1024
MODEL_FILE = "autoencoder_params.keras"

# Define formatting constants (in points and mm)
MM_TO_PT = 2.83465
MM_TO_INCH = 25.4
AXIS_LINEWIDTH = 0 * MM_TO_PT # replace with value
ERRORBAR_LINEWIDTH = 0 * MM_TO_PT # replace with value
TICK_LENGTH = 0 * MM_TO_PT # replace with value
TICK_WIDTH = 0 * MM_TO_PT # replace with value
SCALEBAR_WIDTH = 0 * MM_TO_PT # replace with value
RASTER_WIDTH = 0 * MM_TO_PT # replace with value
RASTER_LENGTH = 0 * MM_TO_PT # replace with value
TRACE_WIDTH = 0 * MM_TO_PT # replace with value
DOT_SIZE = 0 * MM_TO_PT # replace with value

# Font sizes
AXIS_TITLE_SIZE = 8
TICK_LABEL_SIZE = 7
INSET_LABEL_SIZE = 6
FONT_FAMILY = 'Arial'

# Define custom colors
COLORS = {
    'black': (0, 0, 0),
}


# Function to generate a single synthetic AM signal
def generate_am_signal(duration, fs, mod_freq, noise_coeff):
    t = []
    am_signal = []
    for i in range(10):
        t_ = np.linspace(0, duration // 10, int(fs * duration // 10))

        # Modulating wave
        mod_freq = np.random.uniform(0.01, 0.02)
        mod_wave = (np.sin(2 * np.pi * mod_freq * t_) + 1) / 2  # Normalize between 0 and 1
        mod_wave = mod_wave * mod_wave
        
        # Carrier wave (randomized frequency)
        carrier_freq = np.random.uniform(0.5, 0.7)  # Random carrier frequency between 5 Hz and 10 Hz
        carrier_wave = np.sin(2 * np.pi * carrier_freq * t_)

        # Amplitude-modulated signal
        am_signal_ = mod_wave * carrier_wave

        am_signal_random = []
        state = 0 # 0 for cut, 1 for duplicate
        for am in am_signal_:
            if np.random.uniform(0, 1) < 0.3:
                if state == 0:
                    state = 1
                    continue
                else:
                    state = 0
                    am_signal_random.append(am)
            am_signal_random.append(am)

        if len(am_signal_) > len(am_signal_random):
            am_signal_random.append(am_signal_random[-1])
        am_signal_ = np.array(am_signal_random) / 100
        t.append(t_)
        am_signal.append(am_signal_ * np.random.uniform(0.0, 1.2))

    t = np.hstack(t)
    am_signal = np.hstack(am_signal)
    # Add pink noise
    coeff = np.random.uniform(1, 3)
    pink_noise_data = pink_noise(len(t)) / 100
    noisy_signal = am_signal / coeff + 1.5 * coeff * pink_noise_data
    am_signal = am_signal / coeff + 0.1 * coeff * pink_noise_data
    return noisy_signal * 100, am_signal * 100


# Function to generate pink noise
def pink_noise(N):
    uneven = N % 2
    X = np.random.randn(N // 2 + 1 + uneven) + 1j * np.random.randn(N // 2 + 1 + uneven)
    S = np.sqrt(1.0 / (np.arange(len(X)) + 1.0))  # 1/f spectrum
    y = (np.fft.irfft(X * S)).real
    if uneven:
        y = y[:-1]
    return y / np.std(y)
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

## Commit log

2024-01-10 impl ble uart send func
2024-01-12 impl timer
2024-01-19 impl recv twi signals from sensor
2024-07-31 read twi within app timer handler
2024-10-02 fix unpack_sample.py for the new data format
    [unpack_sample.py]
2025-01-27 add kicad pcb data for the custom-made measuring board
    [BOM.csv, transducerBLE.kicad_pcb, transducerBLE.kicad_sch]
